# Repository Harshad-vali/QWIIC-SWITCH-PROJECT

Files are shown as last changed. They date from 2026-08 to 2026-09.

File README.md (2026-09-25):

# Modular I2C GPIO Expander / Power Switch Board (Qwiic-Compatible)

A compact, Qwiic-compatible power switch module built around an I2C GPIO expander, designed for easy integration into modular sensor/electronics setups without extra wiring or a microcontroller doing the switching directly.

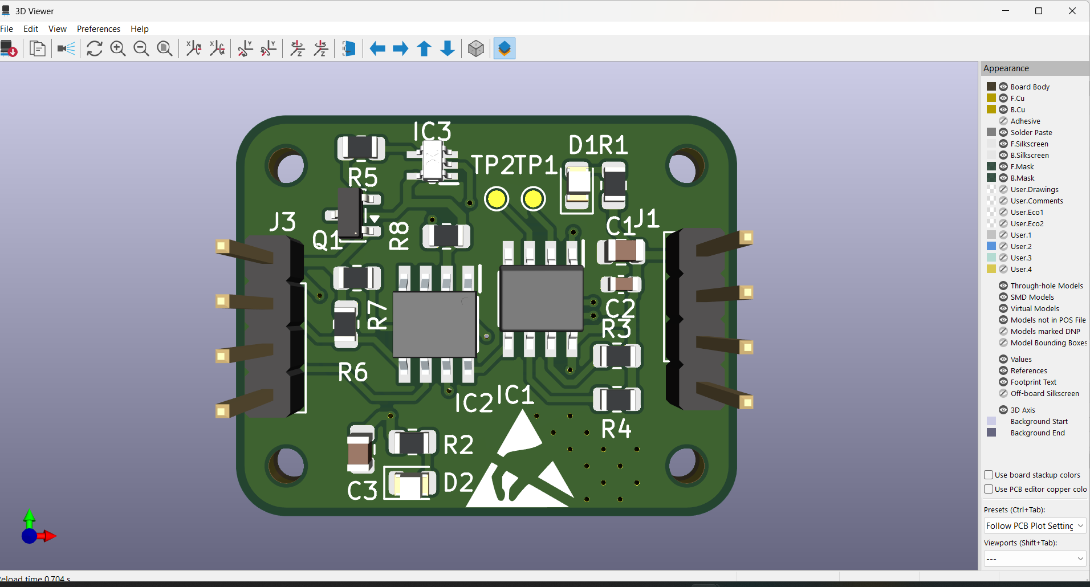
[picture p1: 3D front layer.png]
3D Front View

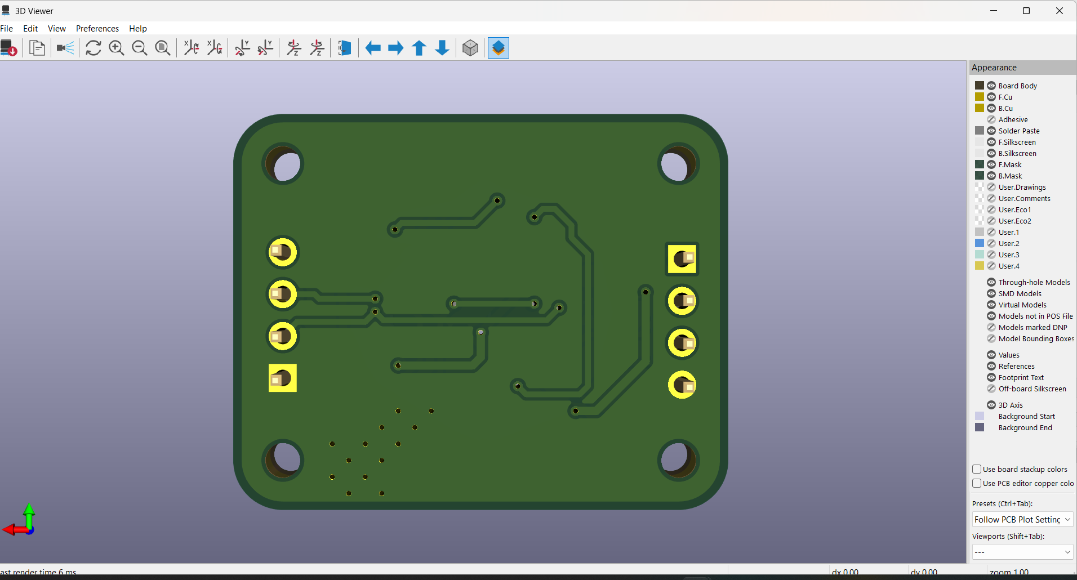
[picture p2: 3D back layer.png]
3D Back View

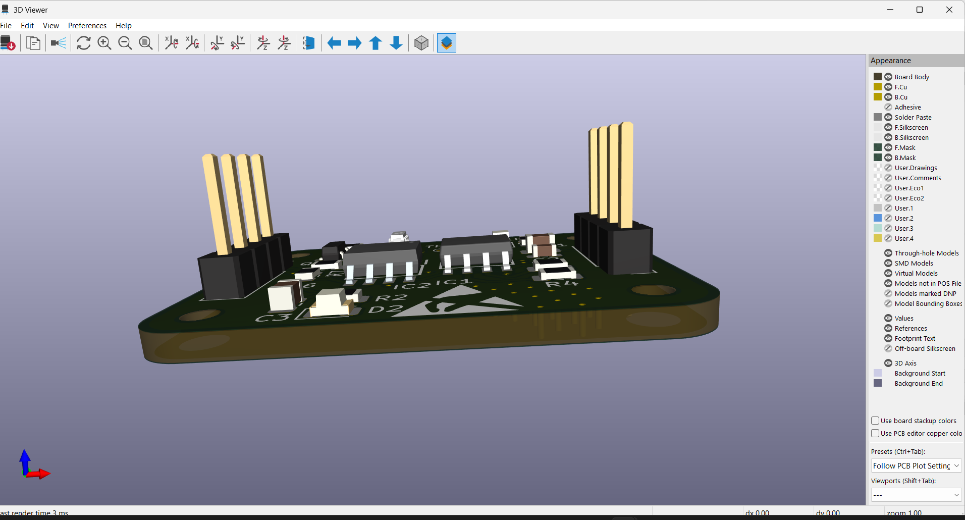
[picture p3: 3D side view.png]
3D Side View


## Overview

This board lets a host microcontroller switch power to a downstream load over I2C, using a GPIO expander instead of dedicated GPIO pins. It's designed to snap into the Qwiic ecosystem, so it can be daisy-chained with other Qwiic boards with no soldering.

## Key Features

- **I2C-controlled power switching** using the PCA9536 GPIO expander
- **PCA9306 I2C level shifter** for safe voltage-level translation between 3.3V and 5V I2C buses
- **Impedance-controlled I2C routing** to keep signal integrity clean on the bus
- **MOSFET switching circuitry** for the actual load power path
- **Status LED indicators** showing real-time switch state at a glance
- **Qwiic-compatible connectors** for plug-and-play integration with other boards

## Design Details

- Schematic capture and PCB layout done fully in KiCad
- Routed with attention to I2C trace impedance to avoid signal integrity issues on the bus
- Component placement optimized for a compact footprint
- Manufacturing-ready output: complete BOM, Gerber files, and drill files generated for fabrication

### Copper Layers

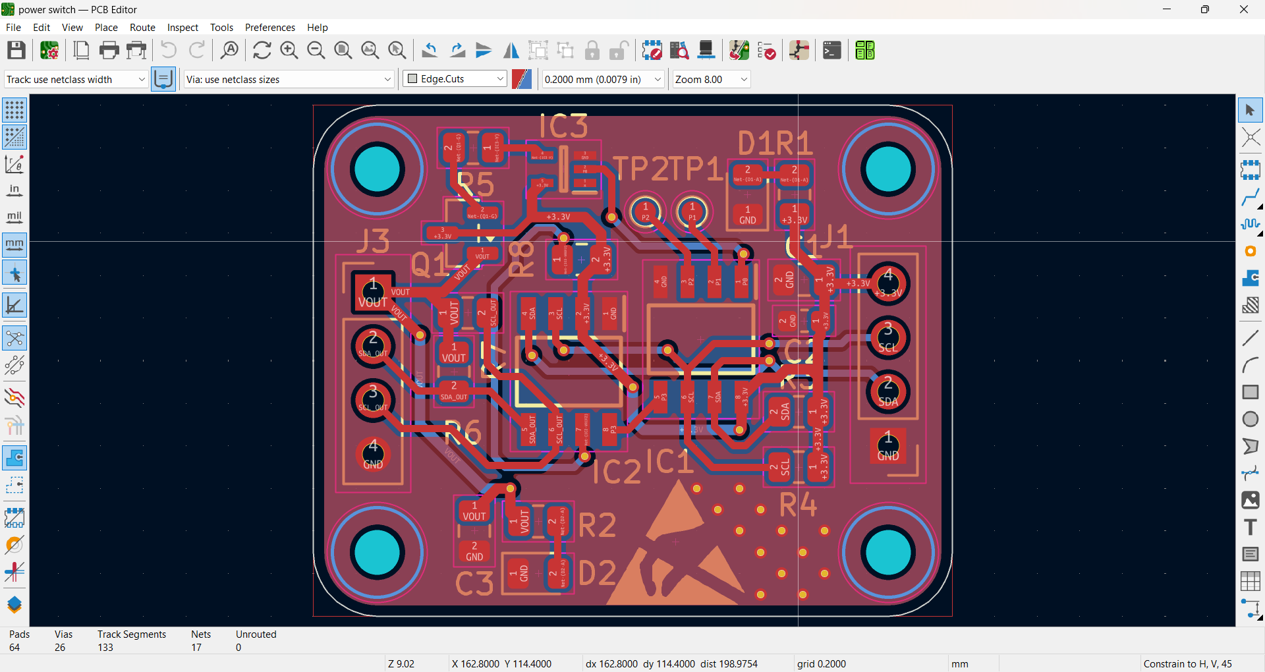
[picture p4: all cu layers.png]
All Copper Layers

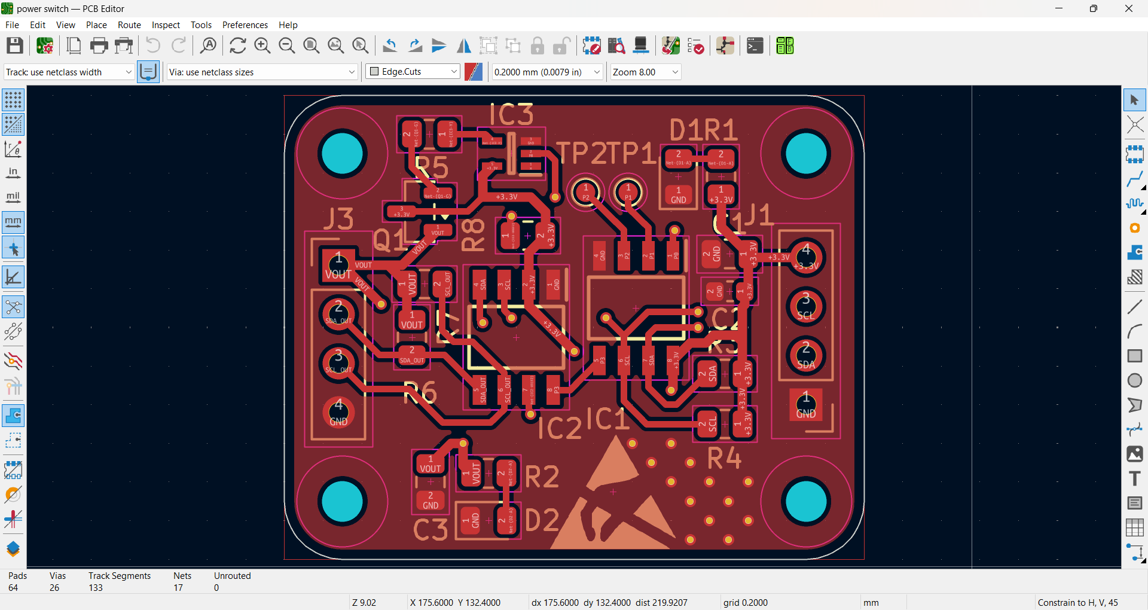
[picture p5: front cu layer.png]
Front Copper Layer

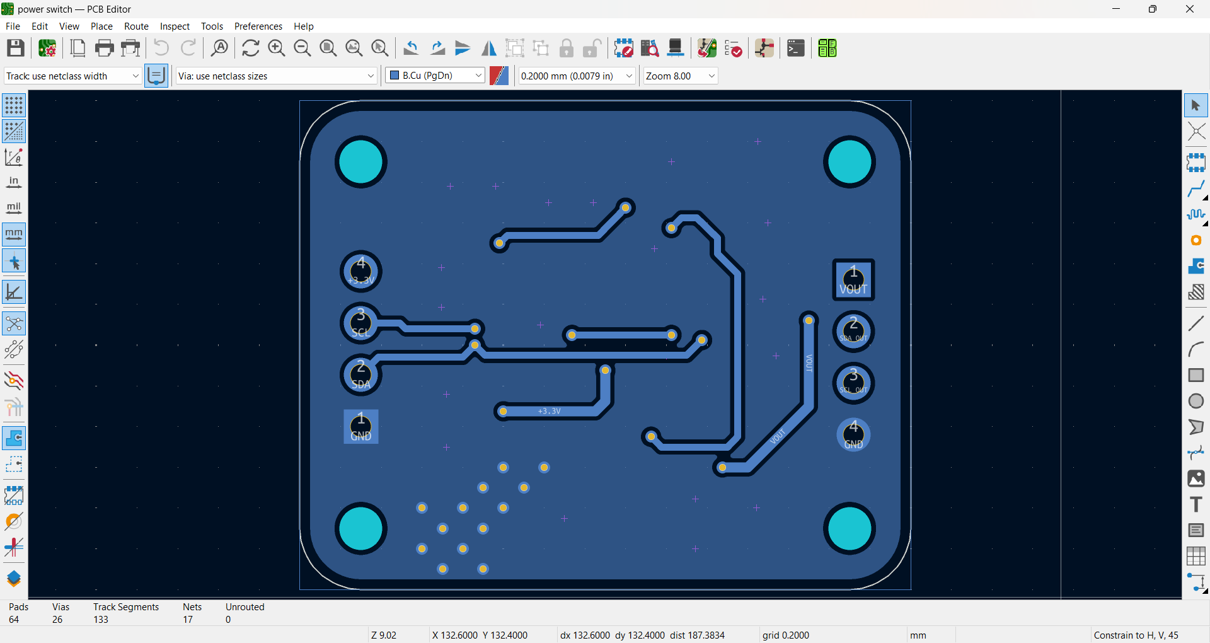
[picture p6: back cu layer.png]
Back Copper Layer


### Assembly Layers

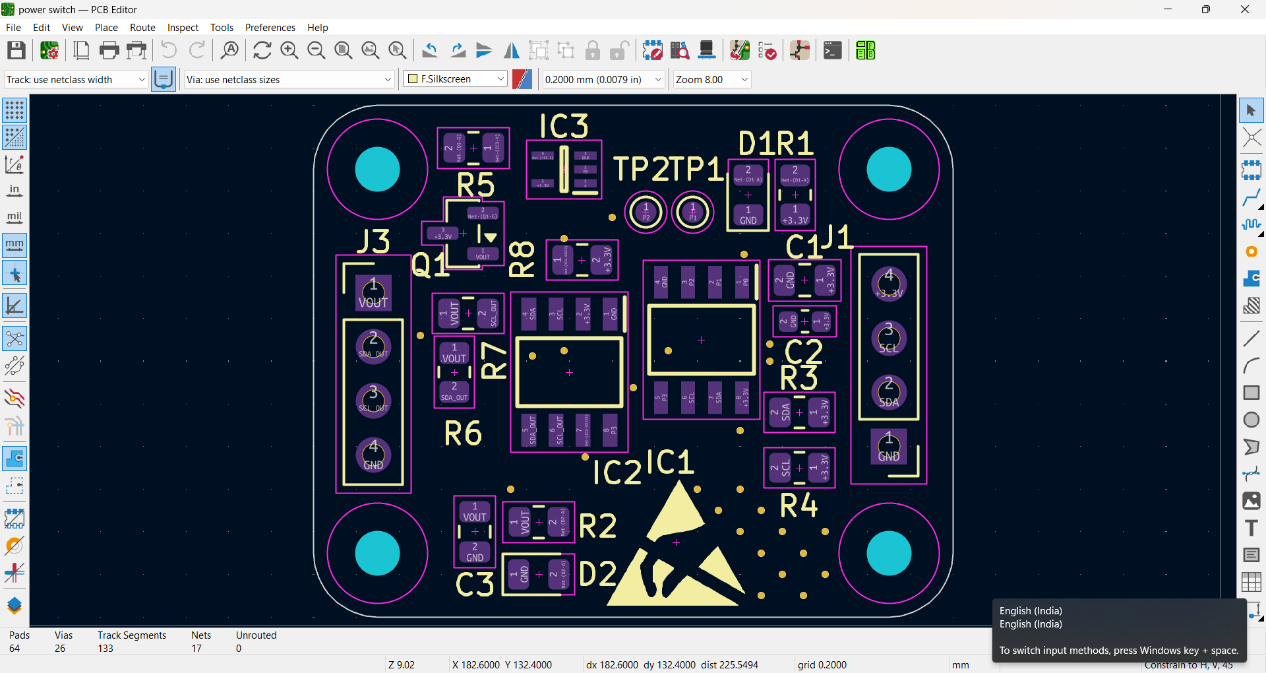
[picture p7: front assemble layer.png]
Front Assembly Layer

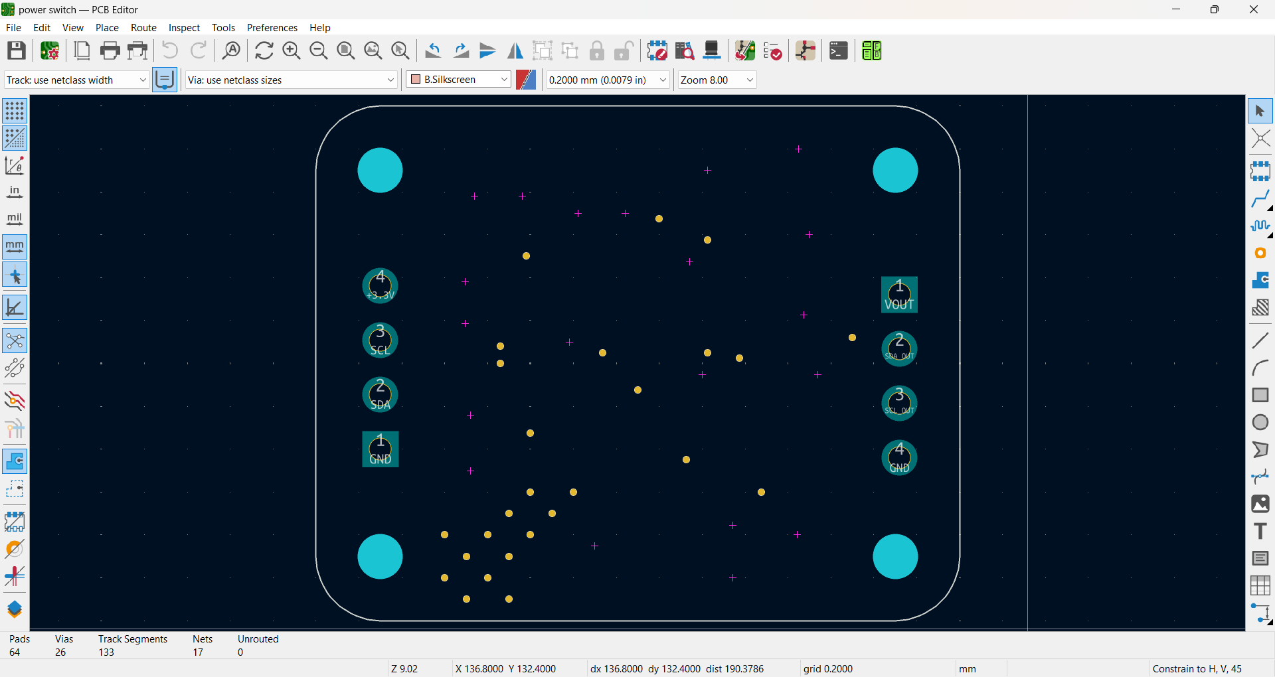
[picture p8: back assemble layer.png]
Back Assembly Layer


### Schematic

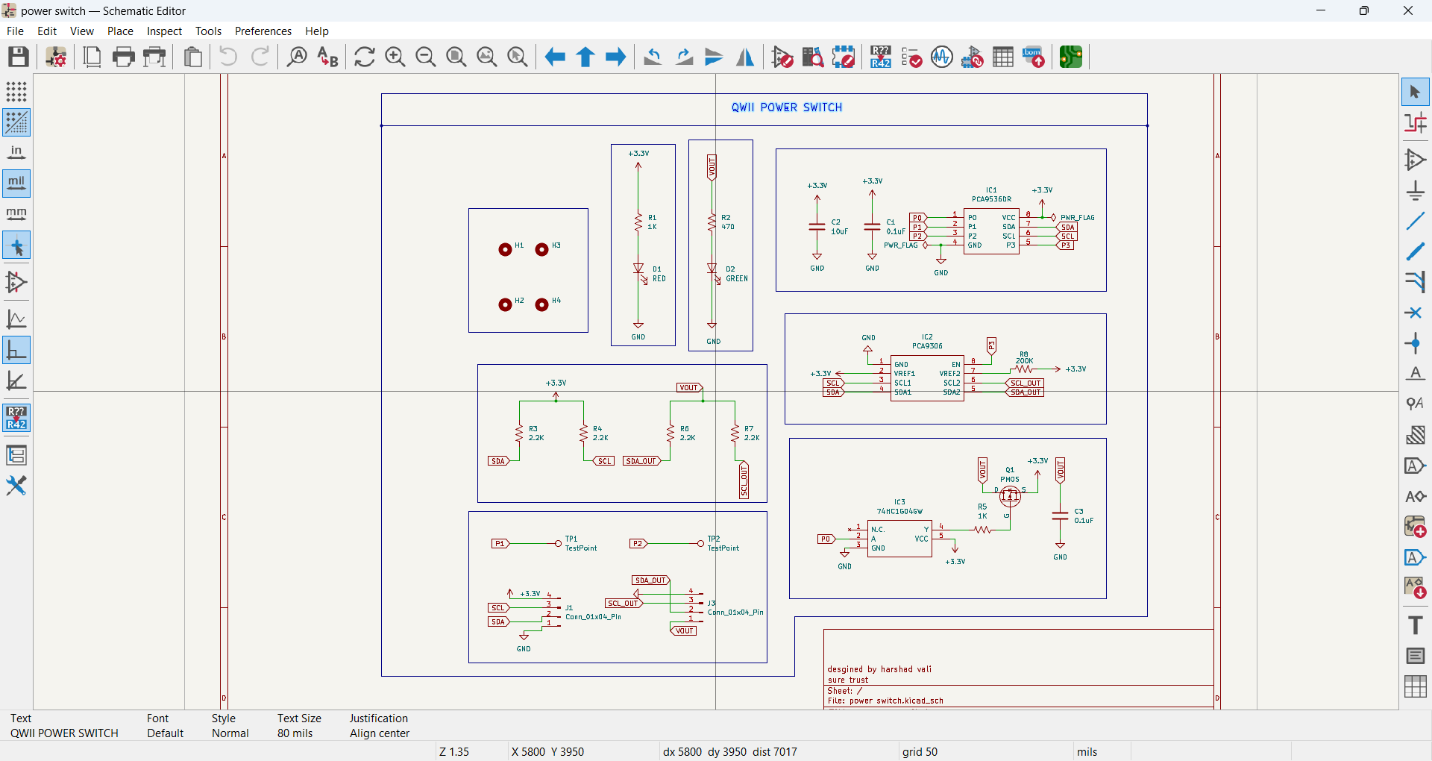
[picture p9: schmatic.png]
Schematic Preview


Full schematic PDF: [Qwiic_Power_Switch_Schematic_v10.pdf](Qwiic_Power_Switch_Schematic_v10%20(1).pdf)

## Tools Used

- KiCad (schematic capture + PCB layout)

## Files in This Repo

- `power switch.kicad_sch` / `power switch.kicad_pcb` / `power switch.kicad_pro` — full KiCad project
- `Qwiic_Power_Switch_Schematic_v10 (1).pdf` — full schematic
- `3D front layer.png`, `3D back layer.png`, `3D side view.png` — 3D renders
- `front cu layer.png`, `back cu layer.png`, `all cu layers.png` — copper layer views
- `front assemble layer.png`, `back assemble layer.png` — assembly drawings
- `schematic.png` — schematic preview image
- `power switch proj 3 main bom.xlsx` — bill of materials with supplier part numbers

## What I'd Improve Next

- Add reverse-polarity protection on the input
- Explore a smaller PCA9536 package option to shrink the footprint further

---
*Part of a PCB design training program (SUREPROED). Designed and routed independently as part of the coursework.*

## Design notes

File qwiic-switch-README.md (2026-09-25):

# Modular I2C GPIO Expander / Power Switch Board (Qwiic-Compatible)

A compact, Qwiic-compatible power switch module built around an I2C GPIO expander, designed for easy integration into modular sensor/electronics setups without extra wiring or a microcontroller doing the switching directly.

PCB Top View
Schematic

## Overview

This board lets a host microcontroller switch power to a downstream load over I2C, using a GPIO expander instead of dedicated GPIO pins. It's designed to snap into the Qwiic ecosystem, so it can be daisy-chained with other Qwiic boards with no soldering.

## Key Features

- **I2C-controlled power switching** using the PCA9536 GPIO expander
- **PCA9306 I2C level shifter** for safe voltage-level translation between 3.3V and 5V I2C buses
- **Impedance-controlled I2C routing** to keep signal integrity clean on the bus
- **MOSFET switching circuitry** for the actual load power path
- **Status LED indicators** showing real-time switch state at a glance
- **Qwiic-compatible connectors** for plug-and-play integration with other boards

## Design Details

- Schematic capture and PCB layout done fully in KiCad
- Routed with attention to I2C trace impedance to avoid signal integrity issues on the bus
- Component placement optimized for a compact footprint
- Manufacturing-ready output: complete BOM, Gerber files, and drill files generated for fabrication

## Tools Used

- KiCad (schematic capture + PCB layout)

## Files in This Repo

- `schematic.pdf` — full schematic
- `pcb-layout/` — top/bottom copper and layer images
- `gerbers/` — manufacturing files (if included)
- `BOM.csv` — bill of materials with supplier part numbers

## What I'd Improve Next

- Add reverse-polarity protection on the input
- Explore a smaller PCA9536 package option to shrink the footprint further

---
*Part of a PCB design training program (SUREPROED). Designed and routed independently as part of the coursework.*

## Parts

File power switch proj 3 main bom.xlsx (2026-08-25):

Reference | Value | Datasheet | Footprint | DNP | Exclude from BOM | Exclude from Board | Qty | Manufacturer_Part_Number | Manufacturer_Name
C1,C3 | 0.1uF | https://www.mouser.in/datasheet/3/508/1/UPY_GPHC_X7R_6_3V_TO_250V.pdf | Capacitor_SMD:C_0805_2012Metric |  |  |  | 2 | CC0805KPX7R9BB104 | YAGEO
C2 | 10uF | https://www.mouser.in/datasheet/3/72/1/KEM_C1006_X5R_SMD.pdf | Capacitor_SMD:C_0603_1608Metric |  |  |  | 1 | C0603C106M9PAC7411 | KEMET
D1 | RED | https://www.we-online.com/components/products/datasheet/150080RS75000.pdf | LED_SMD:LED_0805_2012Metric |  |  |  | 1 | 150080RS75000 | WÃ¼rth Elektronik
D2 | GREEN | https://www.we-online.com/components/products/datasheet/150080GS75000.pdf | LED_SMD:LED_0805_2012Metric |  |  |  | 1 | 150080GS75000 | WÃ¼rth Elektronik
H1,H2,H3,H4 | MountingHole | ~ | MountingHole:MountingHole_2.1mm |  | Excluded from BOM |  | 4
IC1 | PCA9536DR | https://www.ti.com/lit/ds/symlink/pca9536.pdf?HQS=dis-dk-null-digikeymode-dsf-pf-null-wwe&ts=1768324909245 | usb type c:PCA9536 |  |  |  | 1 | PCA9536DR | Texas Instruments
IC2 | PCA9306 | https://www.nxp.com/docs/en/data-sheet/PCA9306.pdf | usb type c:PCA9306 |  |  |  | 1 | PCA9306 | Texas Instruments
IC3 | 74HC1G04GW | https://assets.nexperia.com/documents/data-sheet/74HC_HCT1G04.pdf | usb type c:U1G1 NEW |  |  |  | 1 | 74HC1G04GW,125 | Nexperia
J1,J3 | Conn_01x04_Pin | https://content.harwin.com/m/0351a4d2df127c05/original/DRG-00093-Technical-Drawing-Datasheet-D01-992-pdf.pdf | Connector_PinHeader_2.54mm:PinHeader_1x04_P2.54mm_Vertical |  |  |  | 2 | D01-9922046 | Harwin Inc.
Q1 | PMOS | https://www.panjit.com.tw/upload/datasheet/PJS6631.pdf | Package_TO_SOT_SMD:SOT-23 |  |  |  | 1 | PJS6631_S2_00001 | Panjit International Inc.
R1,R5 | 1K | https://yageogroup.com/content/datasheet/asset/file/PYU-RC_GROUP_51_ROHS_L | Resistor_SMD:R_0805_2012Metric |  |  |  | 2 | RC0805FR-071KL | YAGEO
R2 | 470 | https://yageogroup.com/content/datasheet/asset/file/PYU-RC_GROUP_51_ROHS_L | Resistor_SMD:R_0805_2012Metric |  |  |  | 1 | RC0805FR-07470RL | YAGEO
R3,R4,R6,R7 | 2.2K | https://yageogroup.com/content/datasheet/asset/file/PYU-RC_GROUP_51_ROHS_L | Resistor_SMD:R_0805_2012Metric |  |  |  | 4 | RC0805FR-072K2L | YAGEO
R8 | 200K | https://yageogroup.com/content/datasheet/asset/file/PYU-RC_GROUP_51_ROHS_L | Resistor_SMD:R_0805_2012Metric |  |  |  | 1 | RC0805FR-07200KL | YAGEO
TP1,TP2 | TestPoint | ~ | TestPoint:TestPoint_Pad_D1.0mm |  |  |  | 2

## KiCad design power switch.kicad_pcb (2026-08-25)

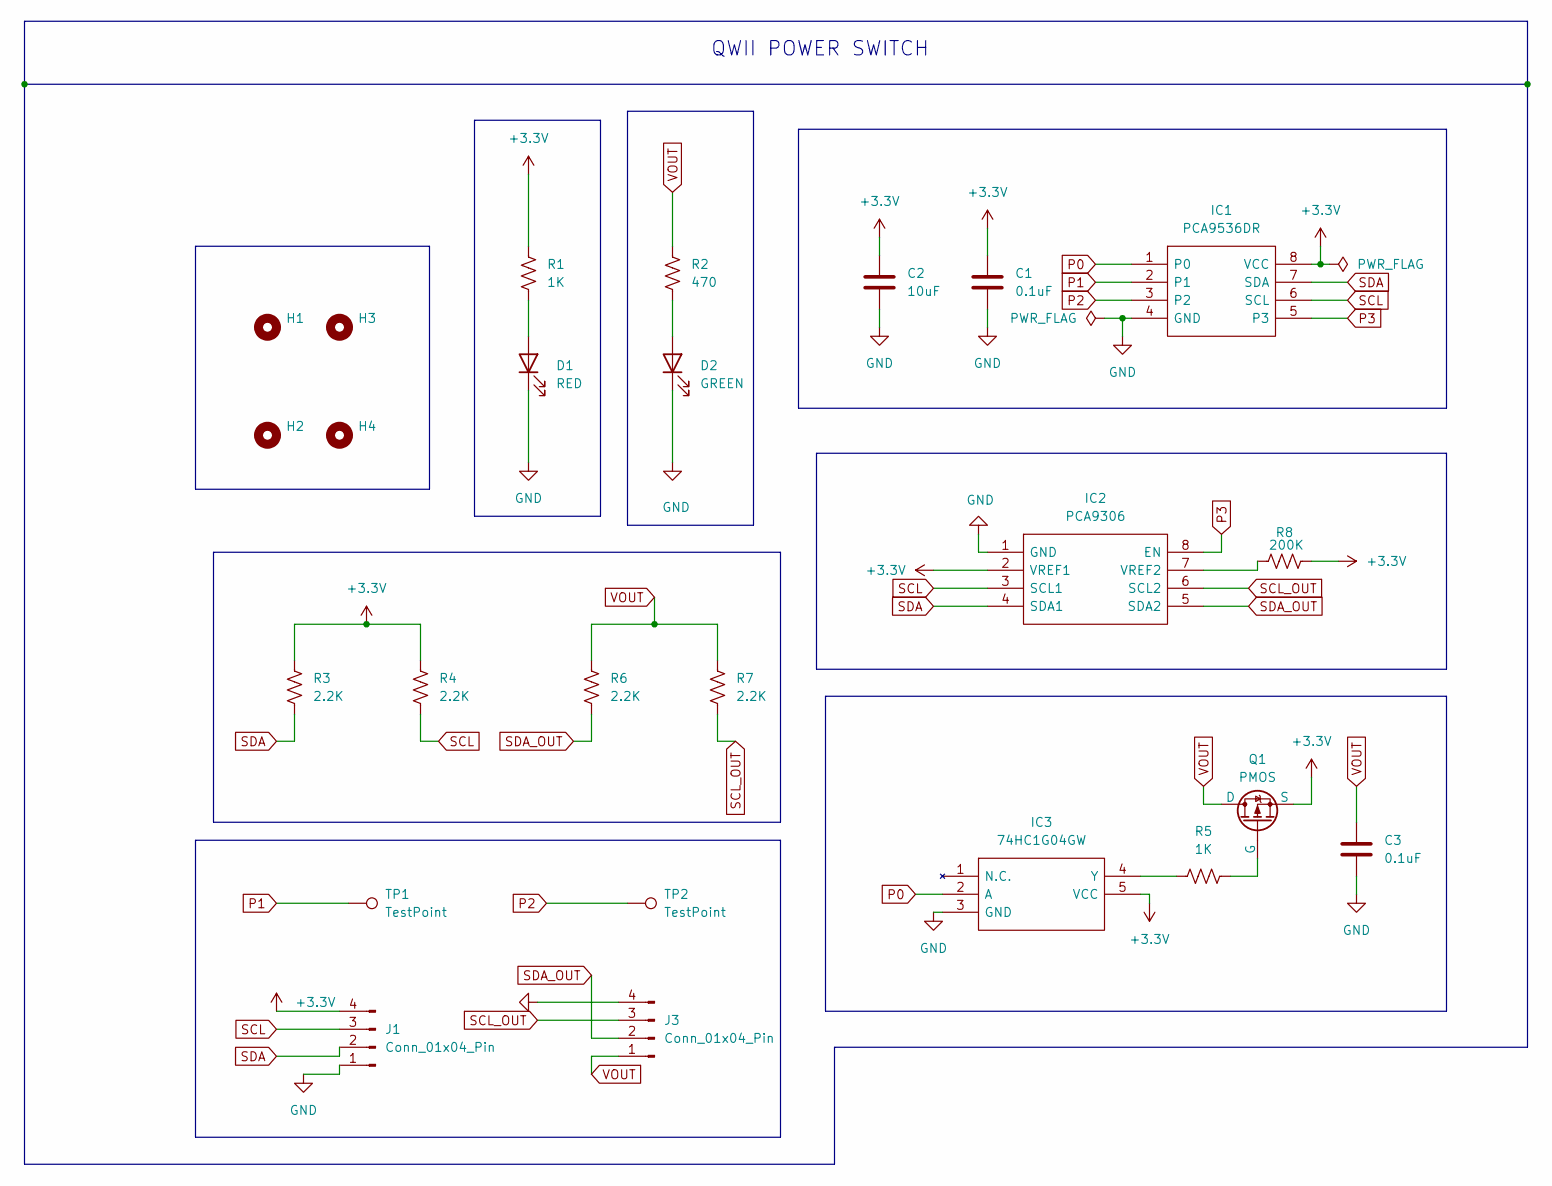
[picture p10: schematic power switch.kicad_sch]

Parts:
C1, C3: 0.1uF; C_0805_2012Metric; Manufacturer_Part_Number CC0805KPX7R9BB104
C2: 10uF; C_0603_1608Metric; Manufacturer_Part_Number C0603C106M9PAC7411
D1: RED; LED_0805_2012Metric; Manufacturer_Part_Number 150080RS75000
D2: GREEN; LED_0805_2012Metric; Manufacturer_Part_Number 150080GS75000
H1, H2, H3, H4: MountingHole; MountingHole_2.1mm
IC1: PCA9536DR; PCA9536; Manufacturer_Part_Number PCA9536DR
IC2: PCA9306; Manufacturer_Part_Number PCA9306
IC3: 74HC1G04GW; U1G1 NEW; Manufacturer_Part_Number 74HC1G04GW,125
J1, J3: Conn_01x04_Pin; PinHeader_1x04_P2.54mm_Vertical; Manufacturer_Part_Number D01-9922046
Q1: PMOS; SOT-23; Manufacturer_Part_Number PJS6631_S2_00001
R1, R5: 1K; R_0805_2012Metric; Manufacturer_Part_Number RC0805FR-071KL
R2: 470; R_0805_2012Metric; Manufacturer_Part_Number RC0805FR-07470RL
R3, R4, R6, R7: 2.2K; R_0805_2012Metric; Manufacturer_Part_Number RC0805FR-072K2L
R8: 200K; R_0805_2012Metric; Manufacturer_Part_Number RC0805FR-07200KL
TP1, TP2: TestPoint; TestPoint_Pad_D1.0mm

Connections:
+3.3V: C1.1, C2.1, IC1.8 (VCC), IC2.2 (VREF1), IC3.5 (VCC), J1.4, Q1.3 (S), R1.1, R3.1, R4.1, R8.2
GND: C1.2, C2.2, C3.2, D1.1 (K), D2.1 (K), IC1.4 (GND), IC2.1 (GND), IC3.3 (GND), J1.1, J3.4
unnamed: D1.2 (A), R1.2
unnamed: D2.2 (A), R2.2
unnamed: IC2.7 (VREF2), R8.1
unnamed: IC3.4 (Y), R5.1
unnamed: Q1.2 (G), R5.2
P0: IC1.1 (P0), IC3.2 (A)
P1: IC1.2 (P1), TP1.1
P2: IC1.3 (P2), TP2.1
P3: IC1.5 (P3), IC2.8 (EN)
SCL: IC1.6 (SCL), IC2.3 (SCL1), J1.3, R4.2
SCL_OUT: IC2.6 (SCL2), J3.3, R7.2
SDA: IC1.7 (SDA), IC2.4 (SDA1), J1.2, R3.2
SDA_OUT: IC2.5 (SDA2), J3.2, R6.2
VOUT: C3.1, J3.1, Q1.1 (D), R2.1, R6.1, R7.1

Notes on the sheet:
QWII POWER SWITCH

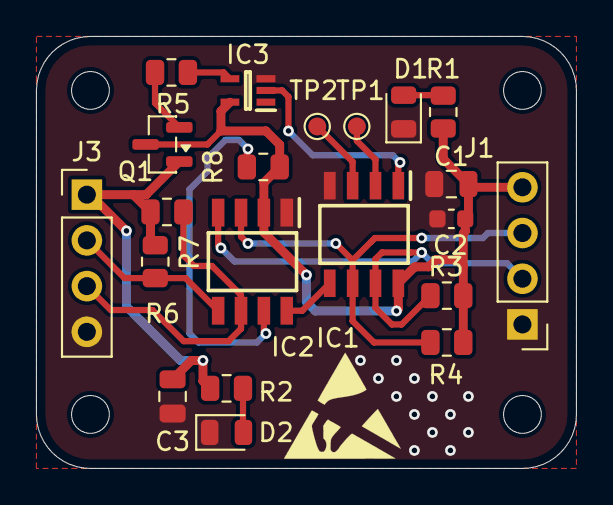
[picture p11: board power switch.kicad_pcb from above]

Board: 2 copper layers, 30.0 x 24.0 mm, 25 parts (0 on the bottom side), 16 nets.

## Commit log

2026-07-06 Update README.md
    MY FRIST KICAD AND PCB DESGING PROOJECT
2026-09-25 Rename 3 front assemble layer.png to front assemble layer.png
2026-09-25 Rename 3 back assemble layer.png to back assemble layer.png
